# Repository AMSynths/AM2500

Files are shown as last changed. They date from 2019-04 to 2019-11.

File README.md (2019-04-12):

# AM2500 DOCUMENTATION REPO

This GitHub repository contains the documentation about the AMSynths 2500 analog synthesizer that is a replica of the ARP 2500 synthesizer from 1970.

There is documentation and open source for each AMSynths module:
* Short form Project Notes
* Eagle CAD schematics and board layouts
* Configuration and setup instructions
* 5U Panel CAD files
* Photographs of the completed modules

The AMSynths website at https://amsynths.co.uk/home/my-synths/2500-rack/ contains more detail on the build status and outcomes and has links to the audio and video demos.

If you need the original schematics go to https://guitarfool.com/ARP2500.html or purchase them from Music Parts at https://www.musicparts.com/products.asp?Company=Arp. I will not be posting the original schematics here.

The AMSynths hardware designs (PCB layouts and schematics,documentation, panel CAD) are licensed as open source under the GNU General Purpose License V3.0.

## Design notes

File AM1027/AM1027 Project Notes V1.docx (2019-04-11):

AMSynths

AM1027

Sequential Controller

Project Notes

V1.0

© AMSynths 2019

Author: Rob Keeble

Contact: info@amsynths.co.uk

Web Site: www.amsynths.co.uk

11 April 2019

ARP Module Description

The 1027 Clocked Sequential Controller is an early analog sequencer which has 10x step rows and 3x control voltage vertical columns. The ARP module is double width and has an analog clock which drives the 3 rows of control voltages on the right. The left hand side of the panel has the clock controls; stop, start, rest, step and frequency. There is also a useful pulse width control.

The AM1027 Circuit

The AMSynths circuit is based around the original ARP schematics with significant changes to implement a 4017 CMOS decade divider chip to replace the very hard to locate Burroughs BIP2611-1 decade “nixie” driver chip that was used in the original.

Using the 4017 inverts the logic state with HIGH being ON and therefore requires downstream changes, and the removal of the power conditioning for the Burroughs chip.

The AM design uses three PCB’s:

- Main divider and output PCB (OUTPUT)
- Analog Clock and Control PCB (SEQ CONTROL)
- CV Potentiometer PCB x3 (POTS)

Overall the 1027 is an easy to build circuit, with no resistor selection required.

SEQ CONTROL PCB

The AMSynths design retains the LM301 Op Amps and uses an encapsulated AM4001 exponential generator sub module with Linear Systems matched transistors.

The original circuit uses 2N3638 transistors to drive the incandescent bulbs in the ON switch, OFF switch and RATE light. These is because each bulb requires 40mA. I have retained the bulbs in the switches but used a LED for the RATE lamp, as it switches on and off faster. The 2N3638 transistors have been successfully replaced with 2N3906 and the TZ581 (Q5) has also been replaced by a 2N3906.

The STEP switch pull up resistor at R31 was changed from 1K to 330R to successfully work.

The trimmers in the design are largely unmarked, this is what they do:

R9 50K - Clock Lower Frequency Trimmer – set to 20 ppm

R12 10K - Clock Upper Frequency Trimmer – set to 440Hz

R19 10K - Pulse Width Trimmer – set to 10%

R22 50K - Clock Waveform Offset –set to 0V

With these changes the analog clock works perfectly.

OUTPUT PCB

Using the 4017 requires a number of changes:

The Transistor Drivers (TD-1 to TD-8) need reconfiguring to use positive logic from the 4017. Q11-Q20 and Q21-Q30 now become 2N3904 transistors, and I have used LED’s as the position lamps which reduces the current being drawn. The 470R resistors at R81- R90 become 330R (giving a gate ON voltage of +9.8V), as the output voltage from the 4017 is higher than the BIP. The pull up resistors at R71 – R80 are removed and this provides +13.4V to the CV potentiometers when HIGH, we will adjust this down to +10V on the POT PCB.

The power conditioning around the BIP2611-1 chip is not needed when using the 4017, so Q33, Q34, CR8, CR9, CR10 and C12 are not required and the 100K pull up resistors at R112 and R114 are removed, and pull down resistors used on the 4017. I have used 10K resistors before the CLOCK and RESET pins, ENABLE is tied to GND.

POTS PCB

This was not in the original design but I have used three of them to make the wiring less complex. Each POT PCB holds the 10 control voltage potentiometers as well as the output summing Op Amps.

R1, R9 and R17 have been increased from 68K to 82K and a 10K trimmer and 91K resistor replace R5, R13 and R21, so we can accurately set the HIGH +10.00V output voltage.

Project Notes Sheet 2 of 3

AM1027 – Sequential Controller

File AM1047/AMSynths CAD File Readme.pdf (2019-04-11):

## AMSynths CAD File Readme

Overview

The front panels for AMSynths production modules are manufactured by Beta Layout in Germany. The CAD files used are specific to Beta Layout and they provide free design software TAREGT 3001.

Here is the website: https://uk.beta-layout.com/frontpanel/

To get a panel manufactured you need to download the software and download the CAD file from the Manuals section of the AMSynths web site. Load the CAD file into the software and order from within the software itself.

Please check the graphics and panel holes look correct before ordering, I usually print the panel onto card and test fit before ordering.

All panels CAD files are released as Open Source Hardware under the MIT license and there is NO warranty that the panels are correct.

Copyright 2019 AMSynths
Permission is hereby granted, free of charge, to any person obtaining a copy of this software and associated documentation files (the "Software"), to deal in the Software without restriction, including without limitation the rights to use, copy, modify, merge, publish, distribute, sublicense, and/or sell copies of the Software, and to permit persons to whom the Software is furnished to do so, subject to the following conditions:

The above copyright notice and this permission notice shall be included in all copies or substantial portions of the Software.

THE SOFTWARE IS PROVIDED "AS IS", WITHOUT WARRANTY OF ANY KIND, EXPRESS OR IMPLIED, INCLUDING BUT NOT LIMITED TO THE WARRANTIES OF MERCHANTABILITY, FITNESS FOR A PARTICULAR PURPOSE AND NONINFRINGEMENT. IN NO EVENT SHALL THE AUTHORS OR COPYRIGHT HOLDERS BE LIABLE FOR ANY CLAIM, DAMAGES OR OTHER LIABILITY, WHETHER IN AN ACTION OF CONTRACT, TORT OR OTHERWISE, ARISING FROM, OUT OF OR IN CONNECTION WITH THE SOFTWARE OR THE USE OR OTHER DEALINGS IN THE SOFTWARE.

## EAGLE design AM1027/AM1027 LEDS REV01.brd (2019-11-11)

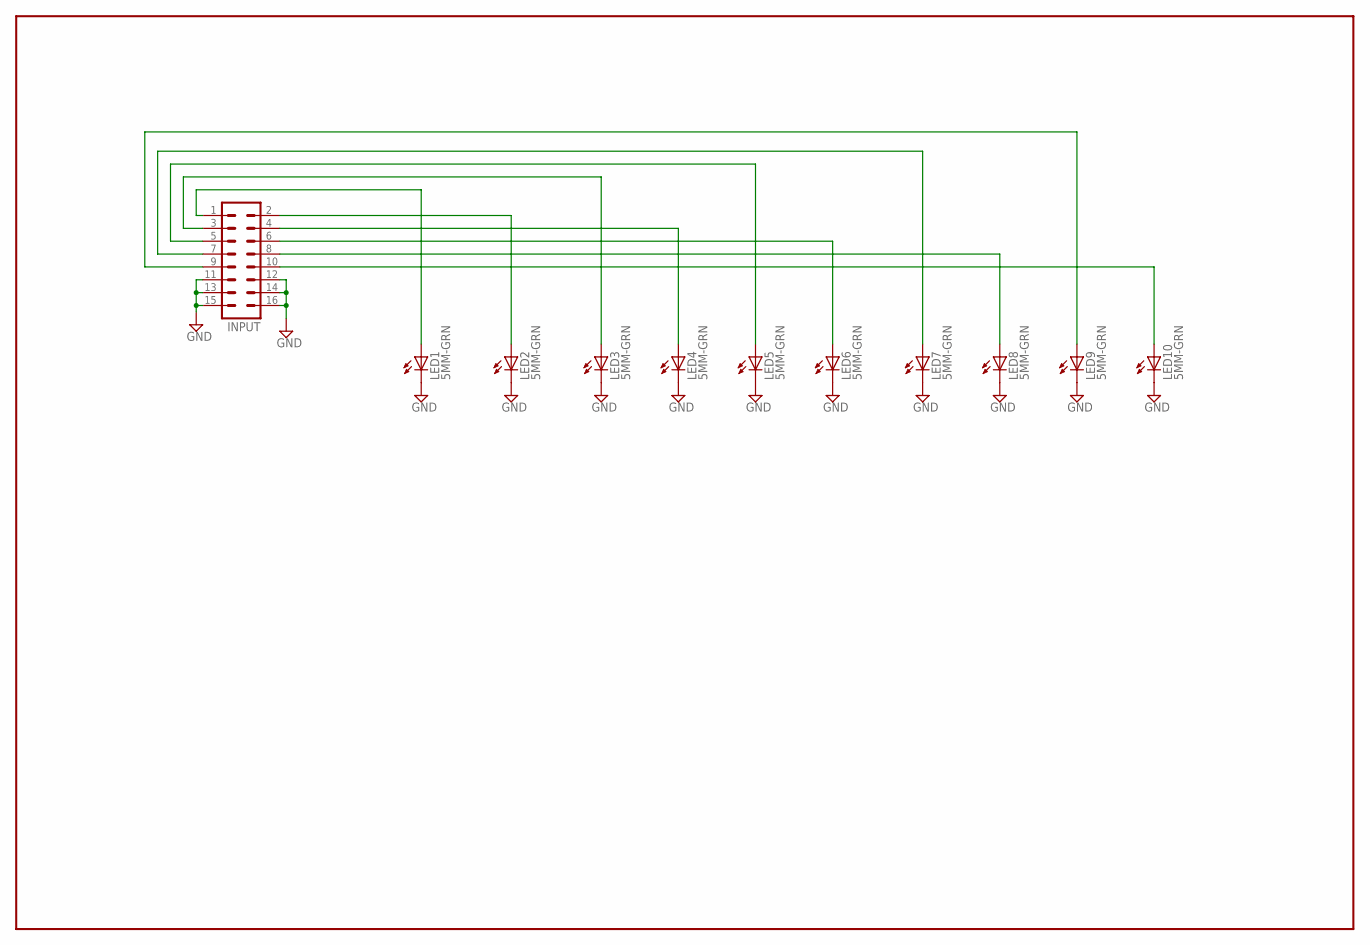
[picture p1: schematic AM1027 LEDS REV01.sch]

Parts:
INPUT: MA08-2-AM
LED1, LED2, LED3, LED4, LED5, LED6, LED7, LED8, LED9, LED10: 5MM-GRN; LED3MM-AMS

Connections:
GND: INPUT.11, INPUT.12, INPUT.13, INPUT.14, INPUT.15, INPUT.16, LED1.C, LED2.C, LED3.C, LED4.C, LED5.C, LED6.C, LED7.C, LED8.C, LED9.C, LED10.C
unnamed: INPUT.2, LED2.A
unnamed: INPUT.1, LED1.A
unnamed: INPUT.3, LED3.A
unnamed: INPUT.4, LED4.A
unnamed: INPUT.5, LED5.A
unnamed: INPUT.6, LED6.A
unnamed: INPUT.7, LED7.A
unnamed: INPUT.8, LED8.A
unnamed: INPUT.9, LED9.A
unnamed: INPUT.10, LED10.A

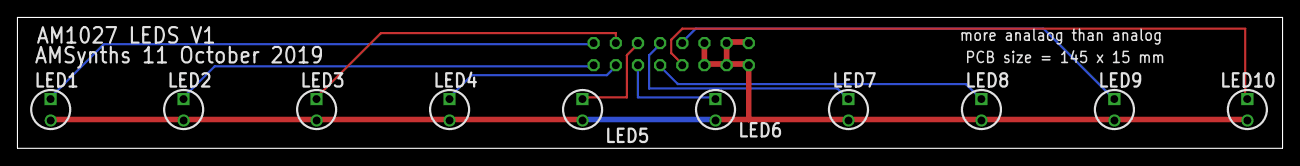
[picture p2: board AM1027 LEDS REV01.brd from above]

Board: 2 copper layers, 145.0 x 15.0 mm, 11 parts (1 on the bottom side), 11 nets.

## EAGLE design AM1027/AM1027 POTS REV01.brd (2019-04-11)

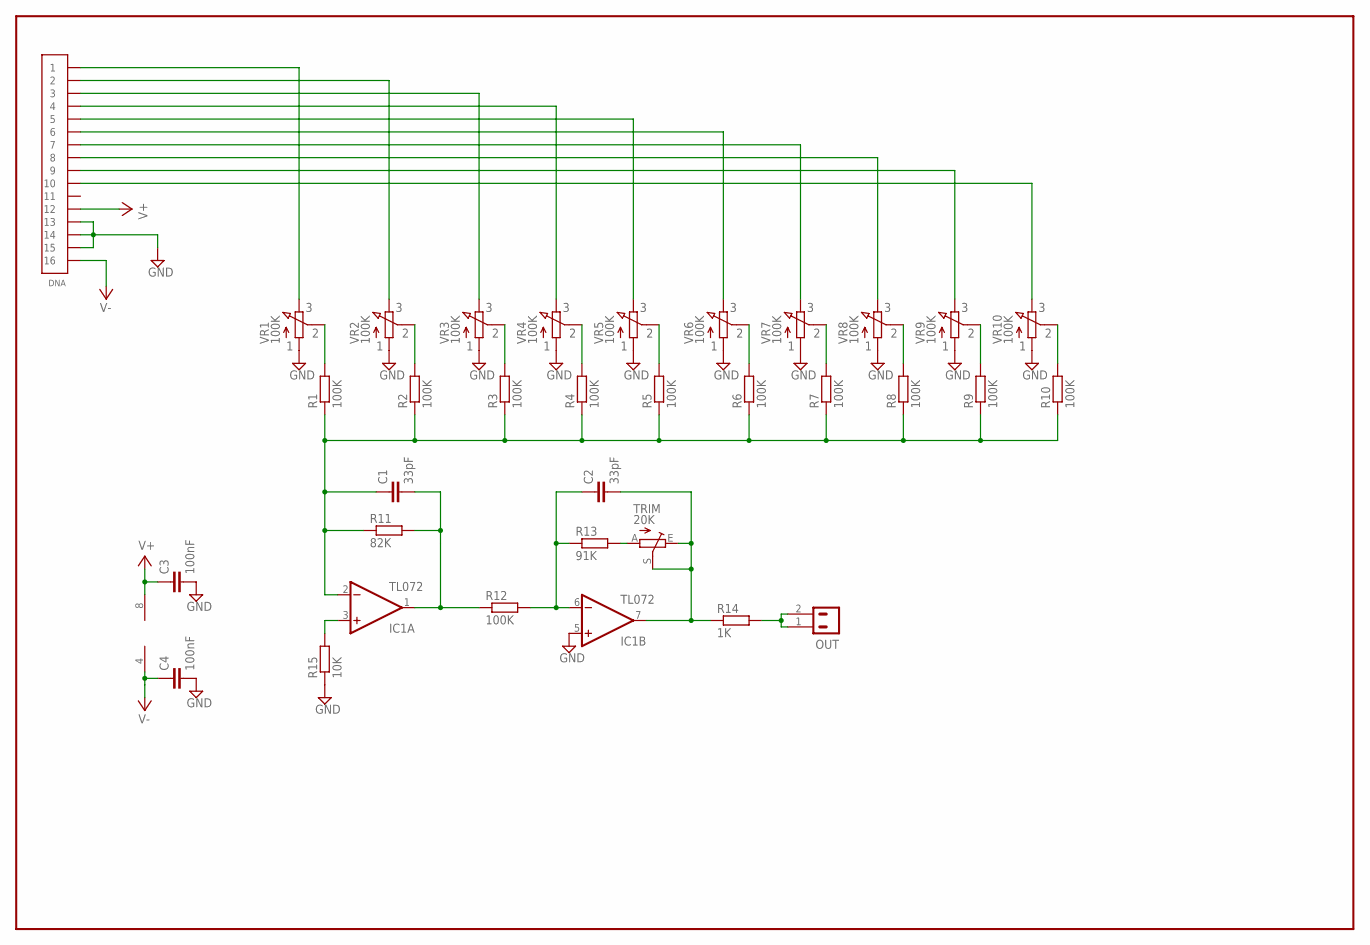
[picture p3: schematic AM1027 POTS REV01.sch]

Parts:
C1, C2: 33pF; C050-025X075AM
C3, C4: 100nF; C050-025X075AM
DNA: AMPWR16PIN; AMPWR16
IC1: TL072; DIL08AM
OUT: MA02-AM
R1, R2, R3, R4, R5, R6, R7, R8, R9, R10, R12: 100K; 0207/10/AM
R11: 82K; 0207/10/AM
R13: 91K; 0207/10/AM
R14: 1K; 0207/10/AM
R15: 10K; 0207/10/AM
TRIM: 20K; S64W-AM
VR1, VR2, VR3, VR4, VR5, VR6, VR7, VR8, VR9, VR10: 100K; SPECTROL148

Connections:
GND: C3.P$4 (2), C4.P$4 (2), DNA.13, DNA.14, DNA.15, IC1.5 (+IN), R15.P$1 (1), VR1.P$1 (A), VR2.P$1 (A), VR3.P$1 (A), VR4.P$1 (A), VR5.P$1 (A), VR6.P$1 (A), VR7.P$1 (A), VR8.P$1 (A), VR9.P$1 (A), VR10.P$1 (A)
unnamed: R1.P$2 (2), VR1.P$2 (S)
unnamed: R2.P$2 (2), VR2.P$2 (S)
unnamed: R3.P$2 (2), VR3.P$2 (S)
unnamed: R4.P$2 (2), VR4.P$2 (S)
unnamed: R5.P$2 (2), VR5.P$2 (S)
unnamed: R6.P$2 (2), VR6.P$2 (S)
unnamed: R7.P$2 (2), VR7.P$2 (S)
unnamed: R8.P$2 (2), VR8.P$2 (S)
unnamed: R9.P$2 (2), VR9.P$2 (S)
unnamed: R10.P$2 (2), VR10.P$2 (S)
unnamed: DNA.1, VR1.P$3 (E)
unnamed: DNA.2, VR2.P$3 (E)
unnamed: DNA.3, VR3.P$3 (E)
unnamed: DNA.4, VR4.P$3 (E)
unnamed: DNA.5, VR5.P$3 (E)
unnamed: DNA.6, VR6.P$3 (E)
unnamed: DNA.7, VR7.P$3 (E)
unnamed: DNA.8, VR8.P$3 (E)
unnamed: DNA.9, VR9.P$3 (E)
unnamed: DNA.10, VR10.P$3 (E)
unnamed: C1.P$3 (1), IC1.2 (-IN), R1.P$1 (1), R2.P$1 (1), R3.P$1 (1), R4.P$1 (1), R5.P$1 (1), R6.P$1 (1), R7.P$1 (1), R8.P$1 (1), R9.P$1 (1), R10.P$1 (1), R11.P$1 (1)
unnamed: C2.P$4 (2), IC1.7 (OUT), R14.P$1 (1), TRIM.E, TRIM.S
unnamed: C1.P$4 (2), IC1.1 (OUT), R11.P$2 (2), R12.P$1 (1)
unnamed: C2.P$3 (1), IC1.6 (-IN), R12.P$2 (2), R13.P$1 (1)
unnamed: IC1.3 (+IN), R15.P$2 (2)
unnamed: R13.P$2 (2), TRIM.A
unnamed: OUT.1, OUT.2, R14.P$2 (2)
V+: C3.P$3 (1), DNA.12, IC1.8 (V+)
V-: C4.P$3 (1), DNA.16, IC1.4 (V-)

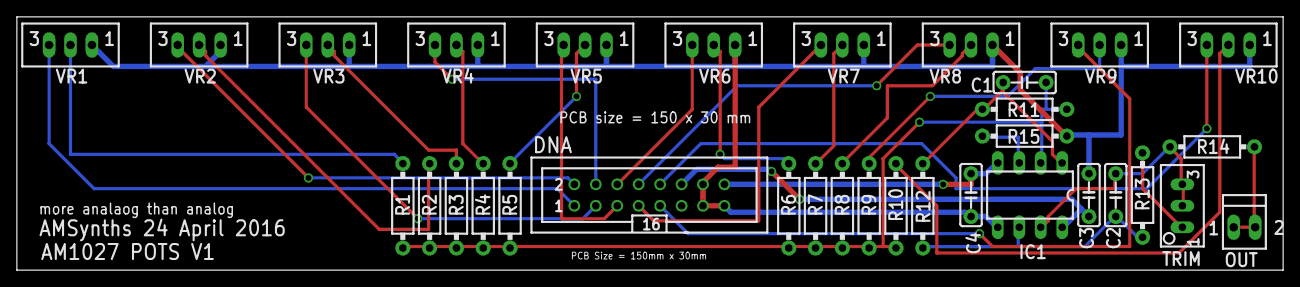
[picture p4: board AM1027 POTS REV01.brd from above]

Board: 2 copper layers, 150.0 x 30.0 mm, 33 parts (0 on the bottom side), 30 nets.

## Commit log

2019-04-11 Eagle CAD files for the POTS PCB
    [AM1027 POTS REV01.brd, AM1027 POTS REV01.sch]
2019-04-11 Panel CAD File for AM1047
    Open with Target V3001! software from BETA-Layout
2019-04-11 Panel CAD file for AM1006
    Open file with TARGET V3001! software from BETA-Layout
